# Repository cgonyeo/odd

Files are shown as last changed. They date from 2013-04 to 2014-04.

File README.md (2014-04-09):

odd
===

One Dimensional Display

http://blog.gonyeo.com/category/odd.html

This project aims to create a single row of RGB LEDs that can be individually 
controlled by a Raspberry Pi. The Pi will be able to display single colors, 
basic hardcoded animations, dynamic animations (like audio visualization), and 
animations in reaction to various events (like someone entered a room, or the 
user reveived a message on Facebook).

The hardware will consist of packages of one TLC5947, eight RGB LEDs, one 
voltage regulator, and some capacitors and resistors on a PCB. These circuit 
boards will be daisy chainable, with an end goal of about 30 boards (240 LEDs).

The hardware will be controlled in roughly the following fashion:

HTML/CSS/Javascript ---> C ---> TLC5947 ---> LEDs

Here's an imcomplete parts list:
 - Raspberry Pi
 - TLC5947 (LED Driver)
 - RGB LEDs (8x the # of TLCs)
 - One of the PCBs from the eagle board folder for each TLC
 - Resistors & capacitors
 - LM3940 (Voltage Regulator)

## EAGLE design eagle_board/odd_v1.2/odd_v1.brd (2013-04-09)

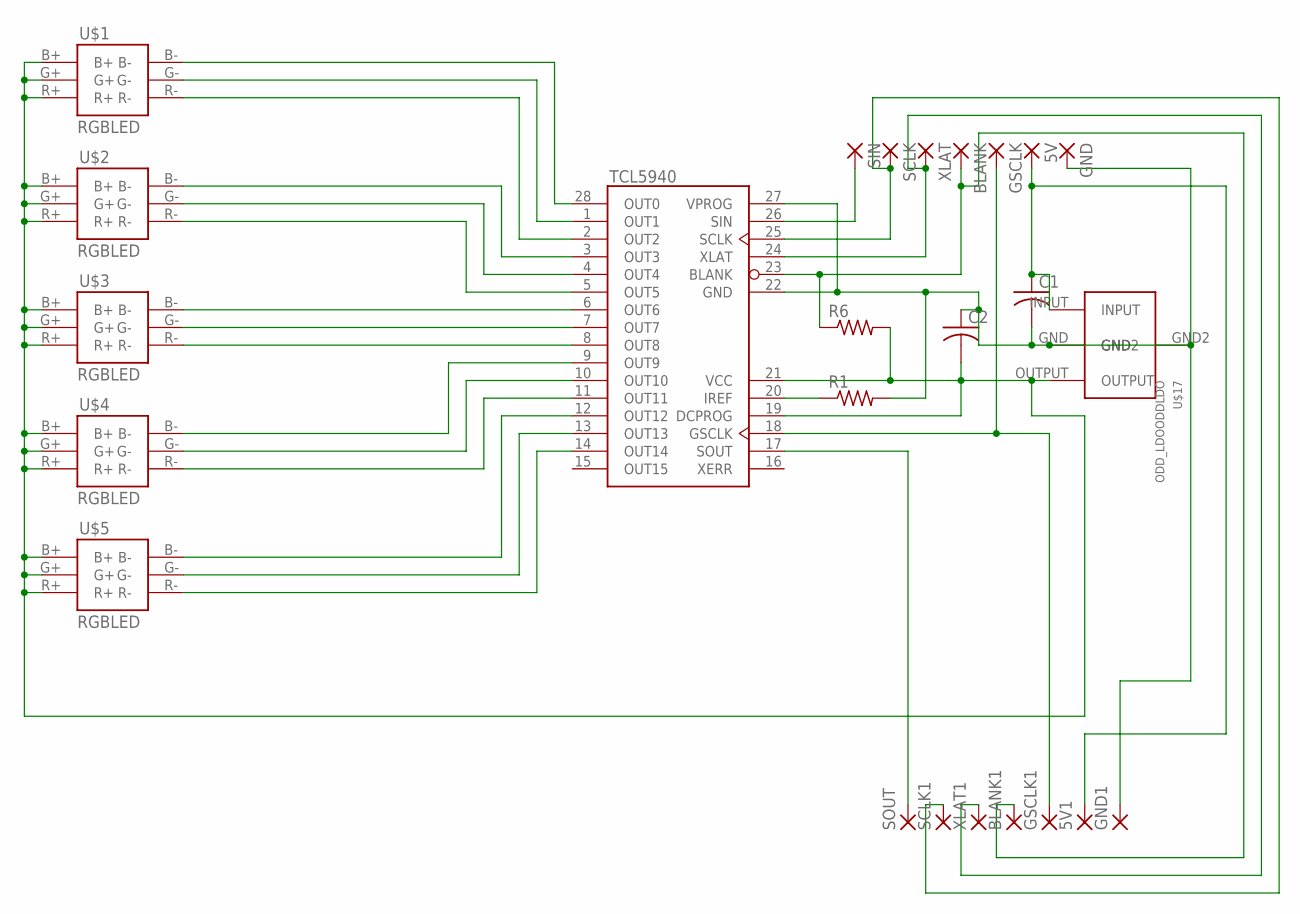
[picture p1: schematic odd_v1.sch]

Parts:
5V, 5V1: 2,54/1,1
BLANK, BLANK1: 2,54/1,1
C1, C2: C-US075-032X103; C075-032X103
GND, GND1: 2,54/1,1
GSCLK, GSCLK1: 2,54/1,1
IC1: TCL5940; DIP28
R1, R6: R-US_0204/7; 0204/7
SCLK, SCLK1: 2,54/1,1
SIN: 2,54/1,1
SOUT: 2,54/1,1
U$1, U$2, U$3, U$4, U$5: RGBLED; 6PADSMD
U$17: ODD_LDOODDLDO; 4PINLDO
XLAT, XLAT1: 2,54/1,1

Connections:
unnamed: IC1.28 (OUT0), U$1.B-
unnamed: IC1.1 (OUT1), U$1.G-
unnamed: IC1.2 (OUT2), U$1.R-
unnamed: IC1.3 (OUT3), U$2.B-
unnamed: IC1.4 (OUT4), U$2.G-
unnamed: IC1.5 (OUT5), U$2.R-
unnamed: IC1.6 (OUT6), U$3.B-
unnamed: IC1.7 (OUT7), U$3.G-
unnamed: IC1.8 (OUT8), U$3.R-
unnamed: IC1.26 (SIN), SIN.1
unnamed: IC1.14 (OUT14), U$5.R-
unnamed: IC1.13 (OUT13), U$5.G-
unnamed: IC1.12 (OUT12), U$5.B-
unnamed: IC1.11 (OUT11), U$4.R-
unnamed: IC1.10 (OUT10), U$4.G-
unnamed: IC1.9 (OUT9), U$4.B-
unnamed: IC1.25 (SCLK), SCLK.1, SCLK1.1
unnamed: 5V.1, 5V1.1, C1.1, U$17.INPUT
unnamed: C1.2, C2.1, GND.1, GND1.1, IC1.22 (GND), IC1.27 (VPROG), R1.2, U$17.GND, U$17.GND2
unnamed: IC1.24 (XLAT), XLAT.1, XLAT1.1
unnamed: GSCLK.1, GSCLK1.1, IC1.18 (GSCLK)
unnamed: C2.2, IC1.19 (DCPROG), IC1.21 (VCC), R6.2, U$1.B+, U$1.G+, U$1.R+, U$2.B+, U$2.G+, U$2.R+, U$3.B+, U$3.G+, U$3.R+, U$4.B+, U$4.G+, U$4.R+, U$5.B+, U$5.G+, U$5.R+, U$17.OUTPUT
unnamed: IC1.17 (SOUT), SOUT.1
unnamed: BLANK.1, BLANK1.1, IC1.23 (BLANK), R6.1
unnamed: IC1.20 (IREF), R1.1

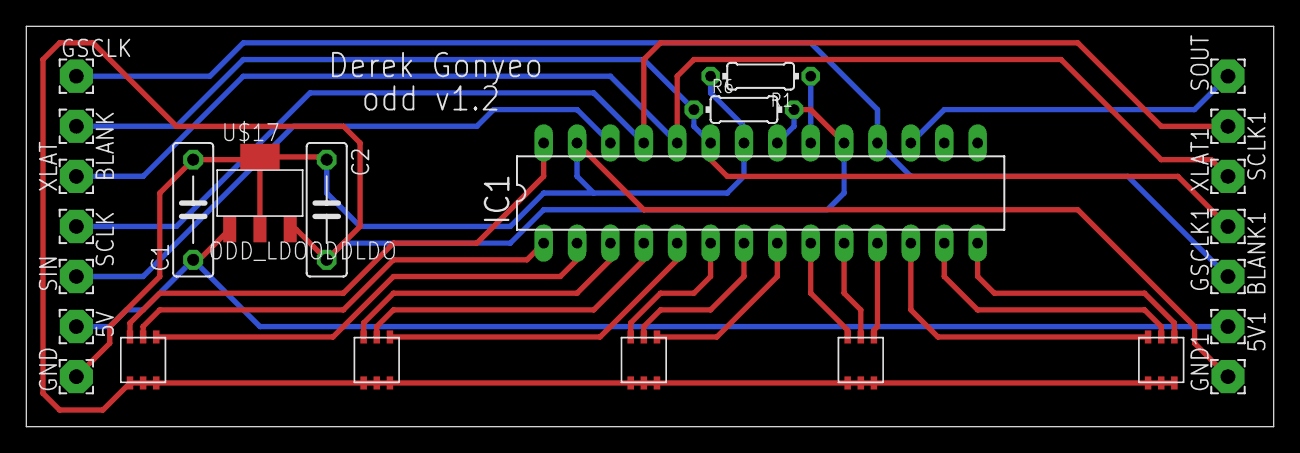
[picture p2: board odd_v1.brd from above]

Board: 2 copper layers, 94.9 x 30.5 mm, 25 parts (0 on the bottom side), 25 nets.

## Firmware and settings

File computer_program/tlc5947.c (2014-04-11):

#include <stdio.h>
#include <stdlib.h>
#include <string.h>
#include <unistd.h>
#include <wiringPi.h>
#include <wiringPiSPI.h>
#include "tlc5947.h"
#include <time.h>

/*
 * Basic Use:
 * Call tlc5947init() before trying to control the chip.
 * Use setLed, setAllLeds, and clearLeds to change the outputs.
 * Once you're happy with the values of each output, call updateLeds() to send this information to the chip.
 * Once you're done, call tlc5947cleanup().
 *
 * To use more than one TLC5947, modify NUM_TLCS in the header file and recompile.
 *
 * Pin Mapping:
 * 
 * 2(27) -> XLAT
 * 3(22) -> BLANK
 *
 * Note: The above follows WiringPi's numbering convention, just google it or something.
 */

#define XLAT 27
#define BLANK 22

typedef unsigned char byte;

int tlcleds[NUM_TLCS * 24];
byte bits[NUM_TLCS * 36];
int xlat_needed = 0;

int spiFile;

//Sets an LED to be a given value
//ledIndex >= 0 && ledIndex < NUM_TLCS * 24
//value >= 0 && value < 4096
void tlcSetLed(int ledIndex, int value)
{
    if(ledIndex >= 0 && ledIndex < NUM_TLCS * 24 && value >= 0 && value < 4096)
        tlcleds[ledIndex] = value;
}

//Sets all LEDs to the given value
//value >= 0 && value < 4096
void tlcSetAllLeds(int value)
{
    if(value >= 0 && value < 4096)
        for(int i = 0; i < NUM_TLCS * 24; i++)
            tlcleds[i] = value;
}

//Sets all channels to 0
void tlcClearLeds(void)
{
    tlcSetAllLeds(0);
}

//index >= 0 && index < NUM_TLCS * 24
//Returns the value of the requested LED, between 0 and 4095 (inclusive)
int tlcGetLedValue(int index)
{
    if(index >= 0 && index < NUM_TLCS * 24)
        return index;
    return -1;
}

//Do nothing 100 times
void delayStuff() 
{
    for(int i = 0; i < 100; i++)
        __asm__ ("nop");
}

//Pulses the given pin. Turns it on, and then off.
void tlcPulsePin(int pin)
{
    digitalWrite(pin, 1);
    delayStuff();
    digitalWrite(pin, 0);
}

//Makes some system calls to set up the GPIO pins,
//and initializes some other stuff
void tlc5947init(void)
{
    char *buffer = malloc(sizeof(char)*60);
    sprintf(buffer, "gpio export %d out", XLAT);
    if(system(buffer) == -1)
        printf("Wiring setup failed!\n");
    sprintf(buffer, "gpio export %d out", BLANK);
    if(system(buffer) == -1)
        printf("Wiring setup failed!\n");
    sprintf(buffer, "gpio load spi");
    if(system(buffer) == -1)
        printf("Wiring setup failed!\n");
    if(wiringPiSetupSys() == -1)
        printf("Wiring setup failed!\n");

    spiFile = wiringPiSPISetup(0, 15000000);
    if(spiFile == -1)
        perror("Error initializing spi things\n");
    
    memset(&tlcleds, 0, sizeof(int));
    free(buffer);
}

//Sets the LEDs to be off
void tlc5947cleanup(void)
{
    tlcSetAllLeds(0);
    tlcUpdateLeds();
}

//[2048,1024,512,256,128,64,32,16,8,4,2,1][2048,1024,512,256,128,64,32,16,8,4,2,1]
//[2048,1024,512,256,128,64,32,16][8,4,2,1,2048,1024,512,256][128,64,32,16,8,4,2,1] <- this but reversed
//We need to write 12 bits for each number, but ints are most definitely larger than that.
//To avoid writing a bunch of leading 0s for every number (which would break things),
//I'm going to fill the 12 least significant bits in to a byte (unsigned char) array, and then write that.
void tlcUpdateLeds(void)
{
    memset(bits, 0, sizeof(byte) * NUM_TLCS * 36);

    int bytecounter = 0;
    for(int i = (NUM_TLCS * 24) - 1; i >= 1; i -= 2)
    {   
        //fill the first byte
        for(int j = 2048; j >= 16; j /= 2)
        {
            bits[bytecounter] |= (tlcleds[i] & j) >> 4;
        }
        //fill the second byte
        bytecounter++;
        for(int j = 8; j >= 1; j /= 2)
        {
            bits[bytecounter] |= (tlcleds[i] & j) << 4;
        }
        for(int j = 2048; j >= 256; j/=2)
        {
            bits[bytecounter] |= (tlcleds[i - 1] & j) >> 8;
        }
        //fill the third byte
        bytecounter++;
        for(int j = 128; j >= 1; j/=2)
        {
            bits[bytecounter] |= tlcleds[i - 1] & j;
        }
        bytecounter++;
    }

    write(spiFile, bits, sizeof(byte) * NUM_TLCS * 36);

    //digitalWrite(BLANK, 1);
    tlcPulsePin(XLAT);
    //digitalWrite(BLANK, 0);
}

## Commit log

2013-02-17 Initial commit. Proof of concept, arduino receives information from computer and updates LEDs to show a basic animation.
2013-02-17 Added an incomplete eagle board.
    [odd_v1.sch]
2013-02-17 Updated board, all desired connections in schematic have been made.
    [odd_v1.sch]
2013-02-18 Schematic modified to only have one TLC590, board made.
    [odd_v1.brd, odd_v1.sch]
2013-02-18 Label added to board.
    [odd_v1.brd]
2013-02-18 Small changes.
    [odd_v1.brd]
2013-02-18 Modified board, there were accidental and dumb connections being made. Also added two capacitors for use with the voltage regulator.
    [odd_v1.brd, odd_v1.sch]
2013-02-19 Modified code to function with two Tlc5940s. Need to add capacitors to prevent decoupling issues to circuit, and then switch back off of bit banging to talk to the ics
2013-02-19 Added threading support and fixed a potential bug with the serial writing. Baud rate also halved.
2013-02-19 LEDs were off by two. Fixed it. Not sure why that was happening or why my fix fixed it, but it fixed it.
2013-02-19 An LED wasn't updating because I told it not to. Removed the code that was doing that.
2013-02-27 Updated the board
    [odd_v1.brd]
2013-03-04 Added an inverse subtract, and fixed bug causing segmentation faults when the arduino is unplugged than the program is exited.
2013-04-01 C driver has been split up into multiple files for better organization, and it now replies on another program to pass it instructions over the network.
2013-04-01 Removed files I never meant to commit, and included Python Websocket -> Socket program (to be used with javascript).
2013-04-02 LEDs are now ontrollable from a website
2013-04-03 Fixed a bug in the arduino code that prevented a channel from updating when daisy chaining the pcbs, (maybe) fixed a time overflow error when running long enough, and fixed a javascript error when en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
2013-04-03 Initial audio support implemented. 3/4 of a second of a lag exists between the computer and the LEDs, so the arduino will need to be removed completely. The driver for the TLC5940s will be rewritten 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
2013-04-09 Updated README to reflect pending removal of the Arduino
2013-04-09 Added a new version of the board, it's now easier to daisy chain and cheaper
    [odd_v1.brd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]
2013-04-11 Working on moving over to Raspberry Pi, driver for the TLC5940 currently doesn't work, and thus LEDs are mostly unusable
2013-04-16 Moved around components on the board to make some paths shorter
    [odd_v1.sch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]
2013-04-22 Updates and stuff
    [odd_v1.sch]
2013-04-22 Advanced page now shows currently running animations on load
2013-05-06 Modified a couple numbers, it now works a lot better.
2013-08-24 Rob fixes things, networking disabled to prevent segfaults.
    [tlc5947.c]
2014-04-11 Fixed cycle/dammit, cleaned up cyloneye
    [tlc5947.c]
